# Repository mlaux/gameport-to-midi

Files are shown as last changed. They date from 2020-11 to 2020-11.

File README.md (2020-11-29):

# Game port to MIDI adapter

This adapter allows the connection of MIDI devices to the 'game port' or joystick port found on old sound cards. It's similar to the reference circuit given in the MIDI specification, but obsolete parts have been replaced with modern equivalents.

KiCad schematic and layout files are provided, as well as three custom footprints (the DIN-5 MIDI connector, the DA-15 game port connector, and the MIDI logo).

<table>
    <tr>
        <td>
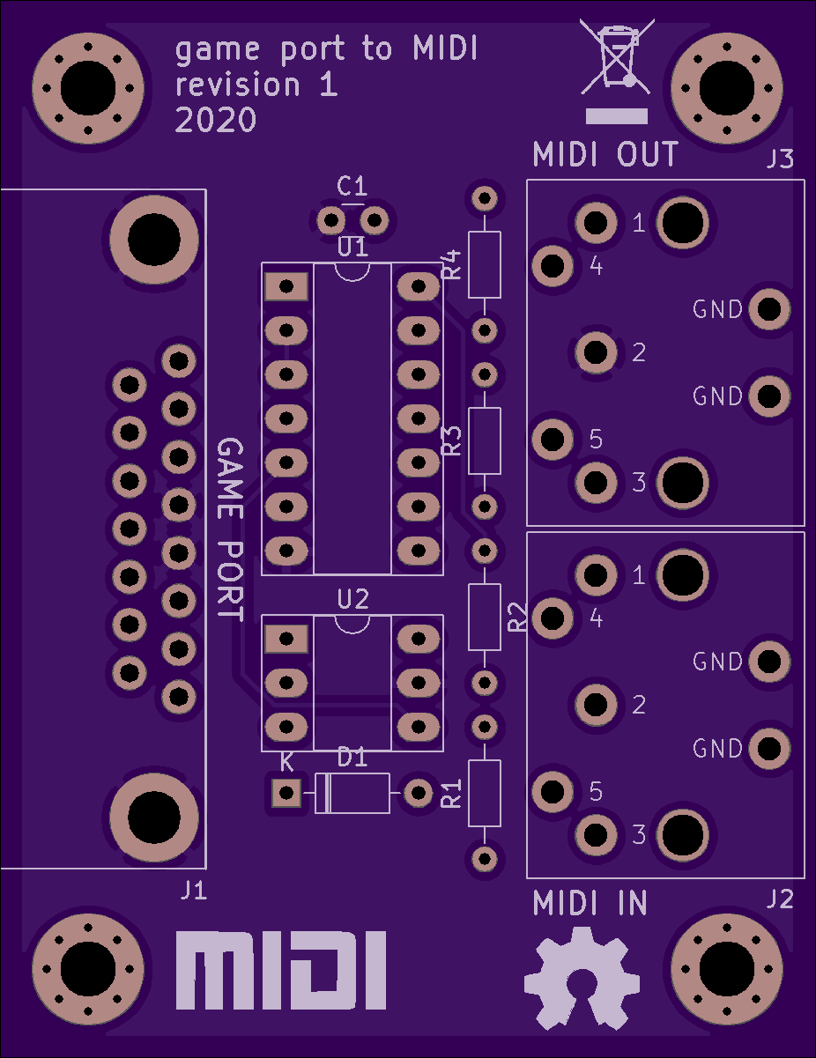
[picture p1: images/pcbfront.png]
            
        </td>
        <td>
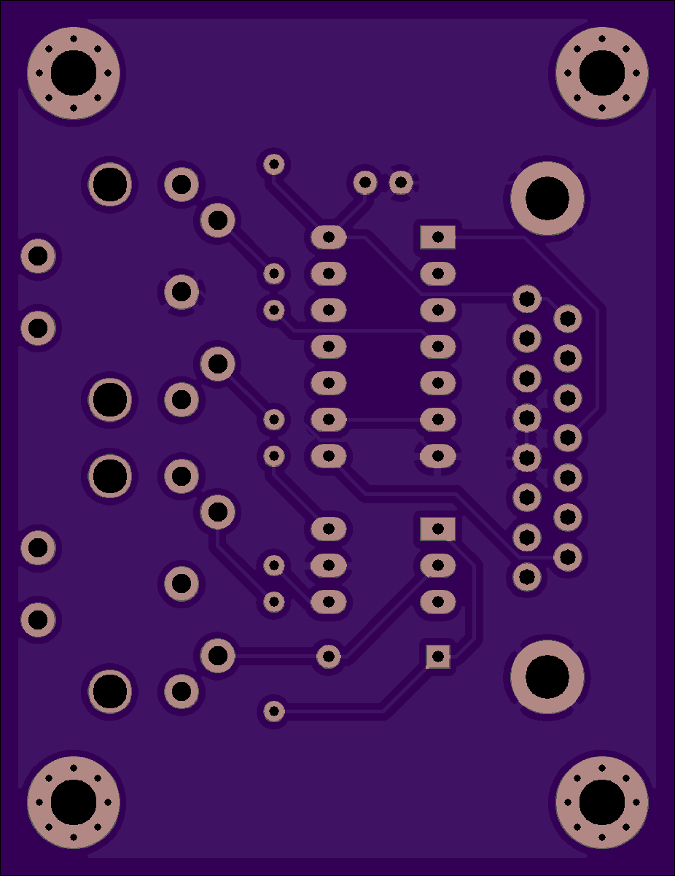
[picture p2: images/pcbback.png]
            
        </td>
    </tr>
</table>

## Bill of Materials

<table>
    <thead>
        <tr>
            <th>Reference</th>
            <th>Value</th>
            <th>Mouser P/N</th>
        </tr>
    </thead>
    <tbody>
        <tr>
            <td>J1</td>
            <td>DA-15 PCB mount connector, pin</td>
            <td>636-182-015-113R531</td>
        </tr>
        <tr>
            <td>J2-J3</td>
            <td>DIN-5 180° socket</td>
            <td>502-57PC5F</td>
        </tr>
        <tr>
            <td>U1</td>
            <td>74HCT04 hex inverter</td>
            <td>595-SN74HCT04N</td>
        </tr>
        <tr>
            <td>U2</td>
            <td>H11L1M optoisolator</td>
            <td>512-H11L1M</td>
        </tr>
        <tr>
            <td>R1-R4</td>
            <td>270 ohm, 1/4 watt</td>
            <td></td>
        </tr>
        <tr>
            <td>C1</td>
            <td>0.1 μF</td>
            <td></td>
        </tr>
        <tr>
            <td>D1</td>
            <td>Small signal, 1N4148</td>
            <td></td>
        </tr>
    </tbody>
</table>

I also recommend IC sockets because they're cheap and look nice.

## License

GNU General Public License v3

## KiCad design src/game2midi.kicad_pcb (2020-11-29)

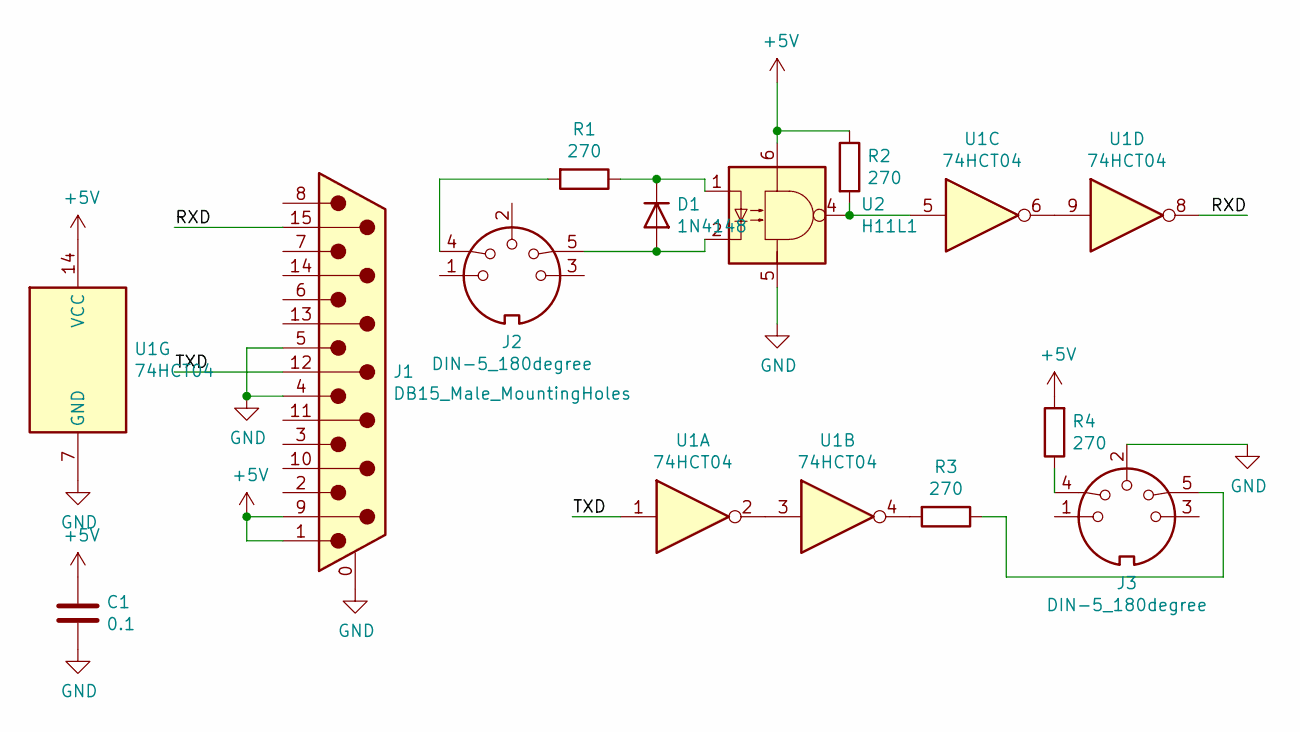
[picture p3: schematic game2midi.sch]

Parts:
C1: 0.1; C_Disc_D3.0mm_W1.6mm_P2.50mm
D1: 1N4148; D_DO-35_SOD27_P7.62mm_Horizontal
J1: DB15_Male_MountingHoles; 182-YYY-113RYY1
J2, J3: DIN-5_180degree; 57PC5F
R1, R2, R3, R4: 270; R_Axial_DIN0204_L3.6mm_D1.6mm_P7.62mm_Horizontal
U1: 74HCT04; DIP-14_W7.62mm_Socket_LongPads
U2: H11L1; DIP-6_W7.62mm_Socket_LongPads

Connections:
+5V: C1.1, J1.1, J1.9, R2.1, R4.2, U1.14 (VCC), U2.6
/RXD: J1.15, U1.8
/TXD: J1.12, U1.1
GND: C1.2, J1.0 (PAD), J1.4, J1.5, J3.2, U1.7 (GND), U2.5
unnamed: D1.1 (K), R1.1, U2.1
unnamed: D1.2 (A), J2.5, U2.2
unnamed: J2.4, R1.2
unnamed: J3.4, R4.1
unnamed: J3.5, R3.1
unnamed: R2.2, U1.5, U2.4
unnamed: R3.2, U1.4
unnamed: U1.2, U1.3
unnamed: U1.6, U1.9

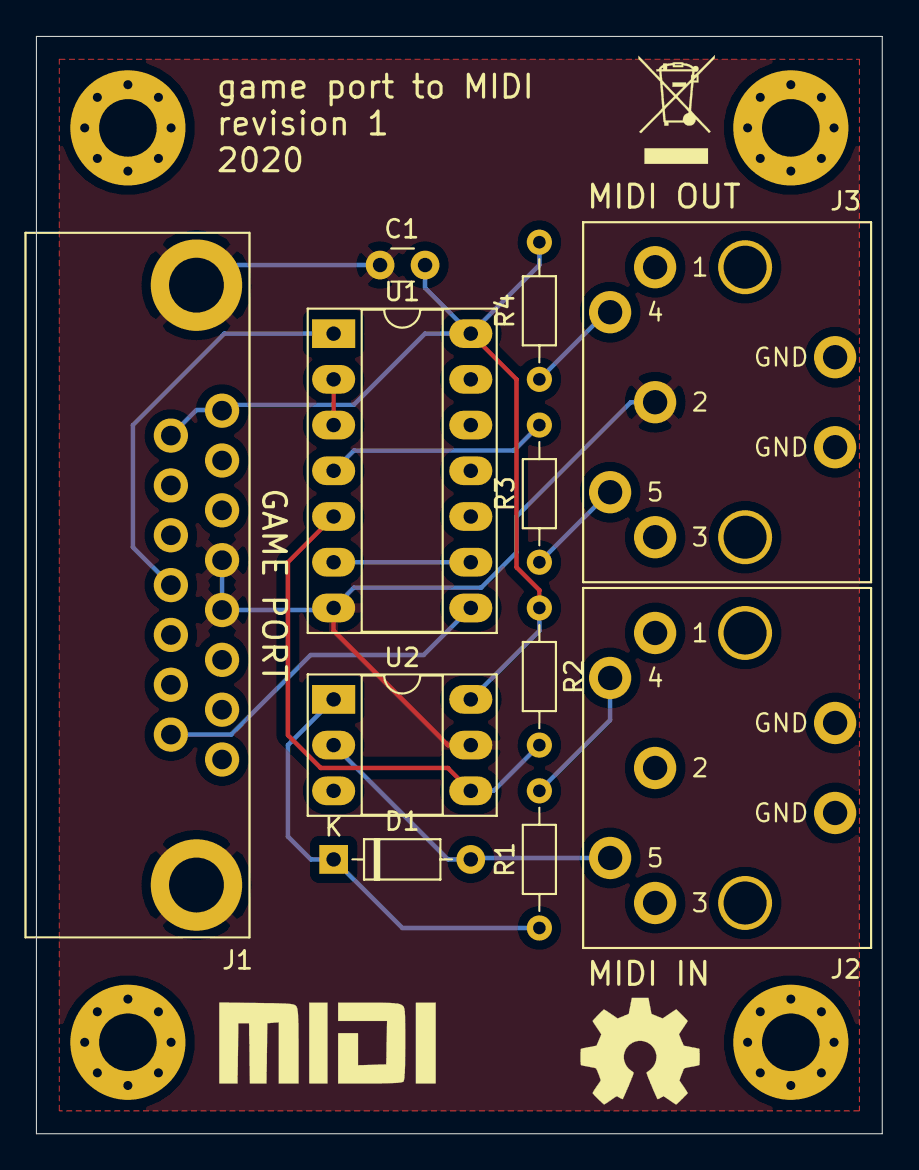
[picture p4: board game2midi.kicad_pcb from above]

Board: 2 copper layers, 47.0 x 61.0 mm, 11 parts (0 on the bottom side), 13 nets.
